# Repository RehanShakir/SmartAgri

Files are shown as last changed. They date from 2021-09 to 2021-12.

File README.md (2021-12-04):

<p align="center">
  <a href="" rel="noopener">
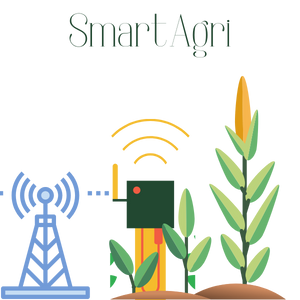
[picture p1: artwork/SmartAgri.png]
Project logo
 </a>
</p>

<h3 align="center">SmartAgri</h3>

<div align="center">

[]()

</div>

---

<p align="center"> SmartAgri
    <br> 
</p>

## 📝 Table of Contents

- [About](#about)
- [Getting Started](#getting_started)
- [Circuit](#circuit)
- [Server Details](#server)
- [MQTT Topic Details](#mqtt)
- [API Details](#api)
- [Usage](#usage)
- [List Of Components](#list)
- [Built Using](#built_using)
- [Authors](#authors)

## 🧐 About 

This repo contains

- Backend
- Firmware
- Client auto-Installer script
- Detailed instructions

for Smart SmartAgri.

## Getting Started 

These instructions will get you a copy of the project up and running on your system.

### Prerequisites

Things you need to install the FW.

```
- Arduino IDE
```

### Installing 

A step by step series that tell you how to get the Firmware and Backend running

#### ESP32 Configuration

You should have Arduino IDE Installed

1.  Add ESP32 Board to your Arduino IDE
1.  In your Arduino IDE, go to File> Preferences
    Installing ESP32 Add-on in Arduino IDE Windows, Mac OS X, Linux open preferences
1.  Enter `https://dl.espressif.com/dl/package_esp32_index.json`
    into the “Additional Board Manager URLs” field then, click the “OK” button:
    Note: if you already have the ESP32 boards URL, you can separate the URLs with a comma(each board will go to neaw line) as follows:
    `https://dl.espressif.com/dl/package_esp32_index.json,\n http://arduino.esp8266.com/stable/package_esp8266com_index.json`

1.  Open the Boards Manager. Go to Tools > Board > Boards Manager…
1.  Search for ESP32 and press install button for the ESP32 by Espressif Systems“:
1.  That’s it. It should be installed after a few seconds.
1.  In your Arduino sketchbook directory, create tools directory if it doesn't exist yet.
1.  Unpack the tool into tools directory(present in libs/ESP32FS-1.0.zip) (the path will look like <home_dir>/Arduino/tools/ESP32FS/tool/esp32fs.jar).
1.  Close and re-open the Arduino IDE.

1.  Now copy the contents of the libs folder to the libraries directory of your Arduino
    1. If you are using windows, the libraries directory will be Documents/Arduino/libraries

##### ESP32 Node FW Uploading

1.  Select ESP32 Dev Module from Tools->Board->ESP32
2.  Select the correct port from Tools->Port
3.  Then open Firmware.ino file,
4.  Select Tools > ESP32 Sketch Data Upload menu item. This should start uploading the files into ESP32 flash file system.
5.  Now Upload the Code to your ESP32 Dev Module.
6.  Your ESP32 is now ready to be used.

## Circuit 

### ESP32 Dev Module Pinout

Follow the pinout diagram given below to connect different components to your ESP32 Dev Module board.

Pinout


### Complete Circuit Diagram

Here's the complete circuit diagram of the system.

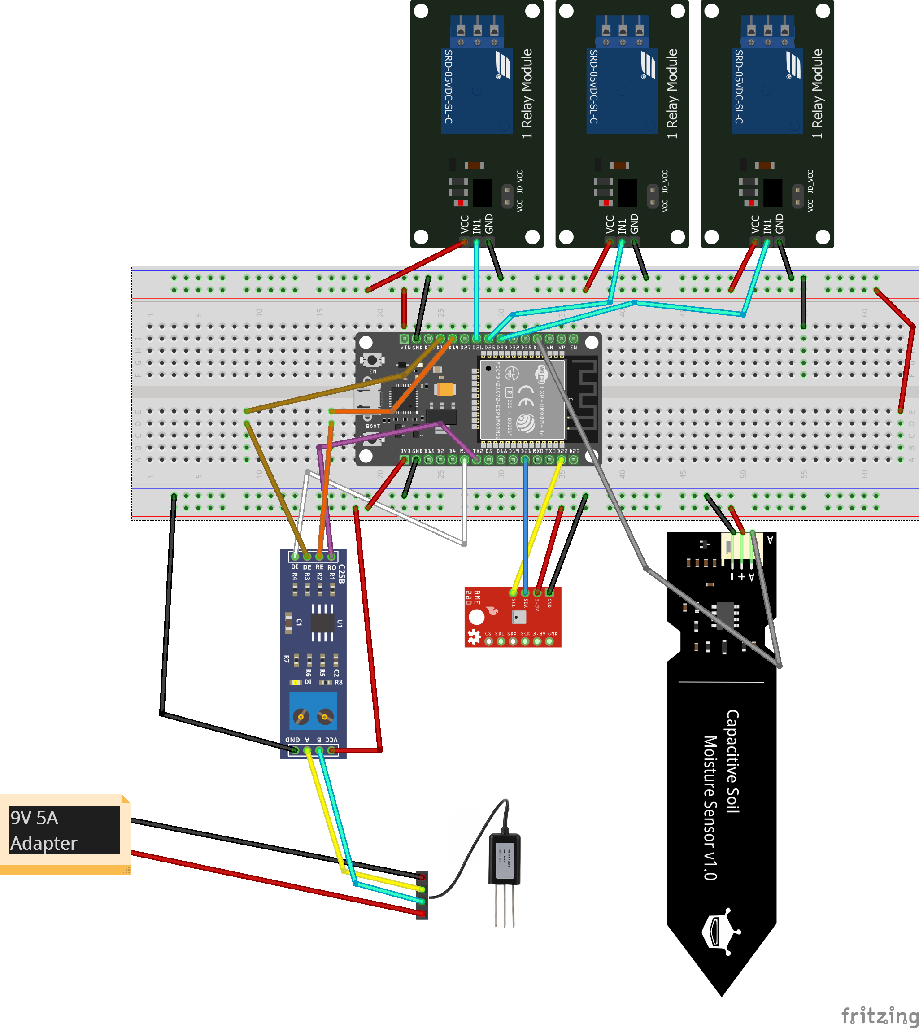
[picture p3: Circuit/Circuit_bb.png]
CircuitDiagram


## Server Details 
### Monitoring

- CapRover

### List of Packages installed on server

- Mosquitto Broker
- NodeJS, NPM, Node, NVM
- PM2
- ufw
- Caprover
- Docker
- mongod
- mongo-express

### Version Details

- Node v12.16.1
- NPM v6.13.4

### Installation of CapRover

#### Pre Reqs
-   You will need to have a domain name in order to use Caprover.
-   Ubuntu 20.04/18.04 VPS with atleast 2GB RAM and 100GB Disk Space.
-   A public IP for VPS.

####  Installation

-   Open the server terminal and execute the following commands
-   ```sudo apt install ufw```
-   ```sudo ufw allow 22```
-   ```sudo ufw allow 1883```
-   ```ufw allow 80,443,3000,996,7946,4789,2377/tcp; ufw allow 7946,4789,2377/udp;```
-   ```sudo ufw enable```
-   ```sudo apt install apt-transport-https ca-certificates curl software-properties-common```
-   ```curl -fsSL https://download.docker.com/linux/ubuntu/gpg | sudo apt-key add -```
-   ```sudo add-apt-repository "deb [arch=amd64] https://download.docker.com/linux/ubuntu focal stable"```
-   ```apt-cache policy docker-ce```
-   ```sudo apt install docker-ce```
-   ```sudo systemctl status docker```
-   The above command will show the status of Dokcer
-   ```sudo usermod -aG docker ${USER}```
-   ```su - ${USER}```
-   ```groups```
-   The above command should show something like *ubuntu sudo docker*
-   ```sudo reboot```
-   Once the server is rebooted run the following commands

##### Step 1
-   ```docker run -p 80:80 -p 443:443 -p 3000:3000 -v /var/run/docker.sock:/var/run/docker.sock -v /captain:/captain caprover/caprover```

You will see a bunch of outputs on your screen. Once the CapRover is initialized, you can visit http://[IP_OF_YOUR_SERVER]:3000 in your browser and login to CapRover using the default password captain42. You can change your password later. However, do not make any changes in the dashboard. We'll use the command line tool to setup the server.
##### Step 2

Let's say you own mydomain.com. You can set *.something.mydomain.com as an A-record in your DNS settings to point to the IP address of the server where you installed CapRover. Note that it can take several hours for this change to take into effect. It will show up like this in your DNS configs:

TYPE: A record
HOST: *.something
POINTS TO: (IP Address of your server)
TTL: (doesn't really matter)
To confirm, go to https://mxtoolbox.com/DNSLookup.aspx and enter randomthing123.something.mydomain.com and check if IP address resolves to the IP you set in your DNS. Note that randomthing123 is needed because you set a wildcard entry in your DNS by setting *.something as your host, not something.

##### Step 3
Assuming you have npm installed on your local machine (e.g., your laptop), simply run (add sudo if needed):

-   ``` sudo npm install -g caprover```
  
Then, run

- ```caprover serversetup```

Follow the steps and login to your CapRover instance. When prompted to enter the root domain, enter something.mydomain.com assuming that you set *.something.mydomain.com to point to your IP address in step #2. Now you can access your CapRover from captain.something.mydomain.com

Note: It will not be possible to carry through with the 'caprover serversetup' if you've already forced https on your CapRover instance.
In such case go straight to logging in with the caprover login command. To change the password go to the settings menu in the app.

#### Deployment

-   Once the CapRover is running, open the dashboard and create 2 new apps named
1.  smart-agri-backend
2.  smart-agri-frontend

Then create go to one click apps and search MongoDB and install it with the following settings

-   Name: smart-agri-database
-   MONGO_INITDB_ROOT_USERNAME: smartAgriDatabase
-   MONGO_INITDB_ROOT_PASSWORD: sma$r$t$Agr$iD$a$%tabase

Once done, go to Web App folder
-   Open frontend root, compress everything as .tar using 7zip or tar if using terminal
-   Open backend folder and again compress everything as .tar
-   Then in caprover open smart-agri-backend->Deployment->Upload & Deploy your .tar file, do the same for front-end as well.

### Server Links 

- MQTT Broker Link: hivemq.com
- Backend Link: http://smart-agri-backend.iot.intelligadgets.me/
- Frontend Link: https://smart-agri-frontend.iot.intelligadgets.me/

### Backend

- Backend is based on NodeJS and it is being managed by Caprover. It starts automatically on server start.

## MQTT Topic Details 

### Topics List

#### Logs

1.  <span style="color: green">smart-agri/logs</span> `(all log messages are published to this topic) READ-ONLY`

#### Fimrware

1.  <span style="color: green">smart-agri/deviceExists</span> `(Publish DeviceMAC on this topic to check if device exisits in DB) WRITE-ONLY`
    1.  <span style="color: green">smart-agri/deviceExistance</span> `(Response from the above command {null or device MAC}) READ-ONLY`

2.  <span style="color: green">data/MAC_ADDRESS</span> `(Publish data to update a device in DB based on its MAC Address.) WRITE-ONLY`
    - Data Format: 
        ```JSON
        {
        "_id":"616fb42d27d2b5351d8a013e",
        "macAddress":"240AC4AFDBDB9C",
        "FW_Version":"v1.0",
        "Environment":
        [
            {
                "Temperautre":12.1,
                "Humidity":54,
                "Atmospheric_Pressure":37.78,
                "_id":"616fb42d27d2b5351d8a013f"
            }
        ],
        "Soil_Parameters":
        [
            {
                "Soil_Moisture":5.44,
                "EC":87.52,
                "pH":47.31,
                "Nitrogen":54.64,
                "Phosphorus":97.13,
                "Potassium":51.03,
                "_id":"616fb42d27d2b5351d8a0140"
            }
        ],
        "createdAt":"2021-10-20T06:16:13.901Z",
        "updatedAt":"2021-10-20T06:16:13.901Z",
        "__v":0
        }
        ```

3.  <span style="color: green">macAddress/relay</span> `(Publish data to control a GPIO(relay/valve) based on SensorNode's MAC Address.) WRITE-ONLY`
    -   Data will be a string "1", "2" or "3"

3.  <span style="color: green">macAddress/settings</span> `(Publish data to set configuration or calibration based on SensorNode's MAC Address.) WRITE-ONLY`
    -   The settings field in the dashboard should contain a valid setting as given below
    1.  "soil_sensor=minLowValue,maxHighValue" (example: soil_sensor=0,550)
    2.  "device_operation=type (example: device_operation=restart)
## API Details 

### Live Sensor Nodes

```http
POST http://smart-agri-backend.iot.intelligadgets.me/api/mqtt
```

| Parameter | Type | Description |
| :--- | :--- | :--- |
| `nothing` | `nothing` | nothing |

-   Returns the list of live sensor nodes

### Users Register

```http
POST http://smart-agri-backend.iot.intelligadgets.me/api/users/register
```

| Parameter  | Type | Description |
| :--- | :--- | :--- |
| `email` | `email address` | **required** enter a valid email address |
| `password` | `password` | **required** enter a password |

-   User registration

### Users Register

```http
POST http://smart-agri-backend.iot.intelligadgets.me/api/users/login
```

| Parameter  | Type | Description |
| :--- | :--- | :--- |
| `email` | `email address` | **required** enter a valid email address |
| `password` | `password` | **required** enter a password |

-   User login

### Responses

Many API endpoints return the JSON representation of the resources created or edited. However, if an invalid request is submitted, or some other error occurs, Gophish returns a JSON response in the following format:

```javascript
{
  "status"  : int,
  "message" : string
}
```

The `message` attribute contains a message commonly used to indicate errors or to return the logged status/

The `status` attribute describes if the transaction was successful or not.

### Status Codes

SmartAgri Backend returns the following status codes in its API:

| Status Code | Description |
| :--- | :--- |
| 200 | `OK` |
| 201 | `CREATED` |
| 400 | `BAD REQUEST` |
| 404 | `NOT FOUND` |
| 500 | `INTERNAL SERVER ERROR` |

## Usage 

1.  Upload the code to your ESP32.
2.  Open the dashboard to monitor the parameters.
    1.  Dashboard Default credentials
        1.  Email Address: **admin@admin.com**
        2.  Password: **admin**

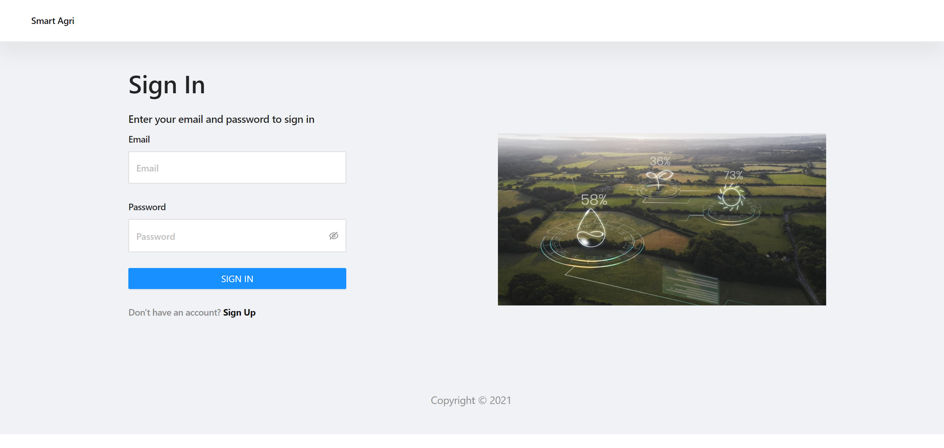
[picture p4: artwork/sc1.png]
SCRD1
Dashboard Login Page
Dashboard Signup PageSCRD2
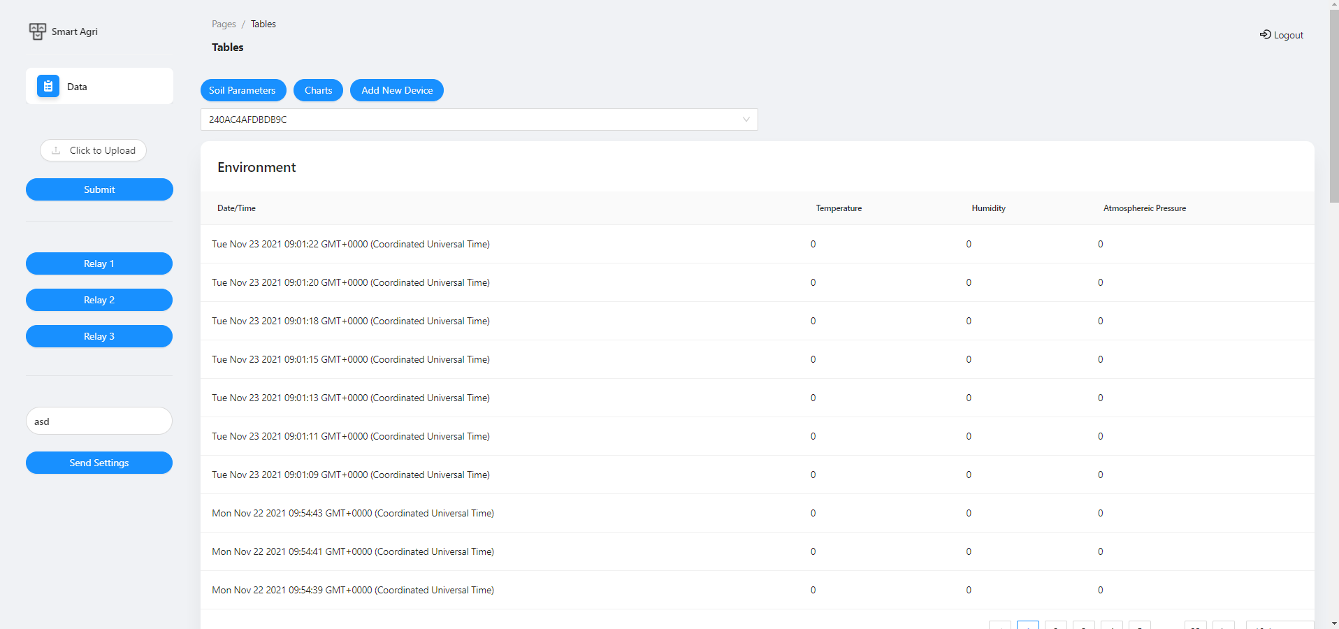
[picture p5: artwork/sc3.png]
SCRD3
Dashboard Home Page
png) 
4. Power on your ESP32, it will present you with an AP named `SmartA-abc` (while `SmartA` can be changed in the portal and `abc` is a unique id for each esp32)
5. Default captive portal password `12345678AP` which can be changed in captive portal. 
6. Connect to the ESP32 access point and open the web-browser and navigate to the link `http://esp32.local/_ac`. This link will work on most of the operating systems but if your operating system is not allowing to open it, you may want to check the captive portal IP Address from the serial monitor and can use that IP address inplace of the above mentioned URL. 
7. The default access IP Address is `http://192.168.4.1/_ac` 8. You will be presented with a main dashboard as shown below(based on your device)
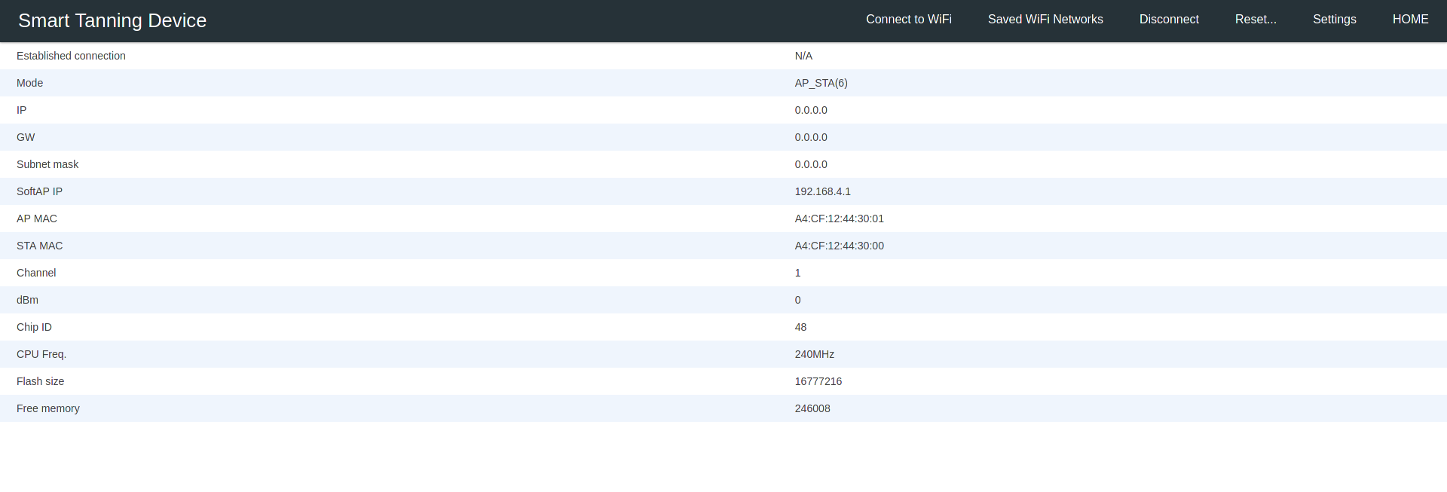
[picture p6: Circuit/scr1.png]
SCR1


8.  Once connected to a WiFi network, you can again access the captive portal using same URL or the IP Address from the Serial monitor.
9.  The data is published to the MQTT Topic `SmartA/{hostname}` while the hostname is the one which you can define in Settings page of the captive portal.
10.  You can open settings page with following default credentials
     1.  User: **AP Name (SmartA)**
     2.  Password: **admin**

## List of Components 

Following components are used to make this project

1.  ESP32 Dev Module
    ○ https://www.amazon.com/ESP32-WROOM-32-Development-ESP-32S-Bluetooth-Arduino/dp/B084KWNMM4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
2.  Atmospheric Temperature and Humidity Sensor (BME280)
    ○ https://www.amazon.com/HiLetgo-Temperature-Humidity-Electronic-Practice/dp/B0795F19W6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
3.  Capacitive Soil Moisture Sensor
    ○ https://www.amazon.com/Icstation-Resistive-Soil-Moisture-Sensor/dp/B076DDWDJK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
4.  NPK Sensor
    ○ https://www.amazon.com/Neufday-Precision-Nutrient-Intelligent-Fertilizer/dp/B0836WYNJ1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
5.  TTL to RS485 Converter
    ○ https://www.amazon.com/HiLetgo-Reciprocal-Hardware-Automatic-Converter/dp/B082Y19KV9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
6.  Soil pH Sensor
    ○ https://www.amazon.com/Taidacent-Detector-Agricultural-Phosphorus-Potassium/dp/B08MXVSKG9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
7.  Soil EC Sensor
    ○ https://www.amazon.com/Taidacent-Detector-Agricultural-Phosphorus-Potassium/dp/B08MXVSKG9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
8.  9V 5A Adapter
    ○ https://www.amazon.com/Supply-Adapter-Converter-Regulator-Monitor/dp/B0888DQ343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
9.  9V to 5V Buck Converter
    ○ https://www.amazon.com/UCTRONICS-Converter-Transformer-Voltage-Regulator/dp/B07XXWQ49N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

## ⛏️ Built Using 

- [NodeJS](https://nodejs.org/en/) - JS Framework for Backend Programming
- [Eclipse Paho MQTT](https://www.eclipse.org/paho/index.php?page=clients/python/index.php) - MQTT Client for Backend and RPiClient Software
- [Arduino](https://www.arduino.cc/) - Embedded Framework and IDE - For Sensor Node Design
- [VueJS](https://vuejs.org/) - For Dashboard Design

## ✍️ Authors 

- [@Nauman3S](https://github.com/Nauman3S) - Development and Deployment

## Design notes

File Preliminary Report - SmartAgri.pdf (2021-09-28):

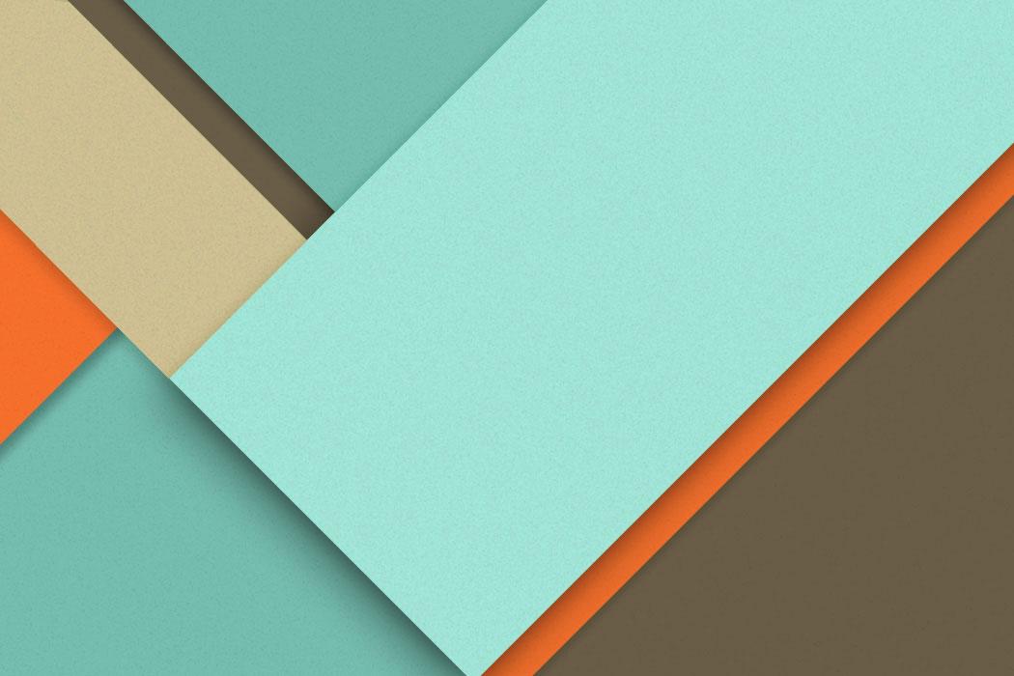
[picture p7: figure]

# SmartAgri

### Preliminary Report V1

09.09.2021
─

## Nauman Shakir

### https://NaumanShakir.com https://3STechLabs.com

## Overview

This preliminary report aims at defining an architecture for SmartAgri systems. The goals of this report are mentioned below

## Goals

1. The system should reduce the time required for a person to be in the field.
2. The system should notify the sensors’ parameters and allow control of different valves and actuators etc via web app.

## Specifications

The system is divided into 3 different layers which should communicate with each other in real-time.

## Layers

- Hardware - Sensor Nodes
- Processing Layer - Server {Ubuntu Server 18.04}
- Application Layer - Mobile and Web Apps

## Components Required

- ESP32 Dev Module
- https://www.amazon.com/ESP32-WROOM-32-Development-ESP-32S-Bluetooth-Arduino/dp/B084KWNMM4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 (https://www.amazon.com/ESP32-WROOM-32-Development-ESP-32S-Bluetooth-Arduino/dp/B084KWNMM4)
- Atmospheric Temperature and Humidity Sensor (DHT22)
- https://www.amazon.com/HiLetgo-Temperature-Humidity-Electronic-Practice/dp/B0795F19W6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 (https://www.amazon.com/HiLetgo-Temperature-Humidity-Electronic-Practice/dp/B0795F19W6)
- Atmospheric Pressure Sensor
- https://www.amazon.com/Gikfun-Barometric-Pressure-Temperature-EK1214x3/dp/B07Q3PQ81R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 (https://www.amazon.com/Gikfun-Barometric-Pressure-Temperature-EK1214x3/dp/B07Q3PQ81R)
- Soil Moisture Sensor
- https://www.amazon.com/Icstation-Resistive-Soil-Moisture-Sensor/dp/B076DDWDJK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 (https://www.amazon.com/Icstation-Resistive-Soil-Moisture-Sensor/dp/B076DDWDJK)
- NPK Sensor
- https://www.amazon.com/Neufday-Precision-Nutrient-Intelligent-Fertilizer/dp/B0836WYNJ1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 (https://www.amazon.com/Neufday-Precision-Nutrient-Intelligent-Fertilizer/dp/B0836WYNJ1)
- RS485 Converter for NPK Sensor
- https://www.amazon.com/Max485-Chip-RS-485-Module-Raspberry/dp/B00NIOLNAG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 (https://www.amazon.com/Max485-Chip-RS-485-Module-Raspberry/dp/B00NIOLNAG)
- Soil pH Sensor
- https://www.amazon.com/Taidacent-Detector-Agricultural-Phosphorus-Potassium/dp/B08MXVSKG9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 (https://www.amazon.com/Taidacent-Detector-Agricultural-Phosphorus-Potassium/dp/B08MXVSKG9)
- Soil EC Sensor
- https://www.amazon.com/Taidacent-Detector-Agricultural-Phosphorus-Potassium/dp/B08MXVSKG9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 (https://www.amazon.com/Taidacent-Detector-Agricultural-Phosphorus-Potassium/dp/B08MXVSKG9)
- 9V 5A Adapter
- https://www.amazon.com/Supply-Adapter-Converter-Regulator-Monitor/dp/B0888DQ343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 (https://www.amazon.com/Supply-Adapter-Converter-Regulator-Monitor/dp/B0888DQ343)

- 9V to 5V Buck Converter
- https://www.amazon.com/UCTRONICS-Converter-Transformer-Voltage-Regulator/dp/B07XXWQ49N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 (https://www.amazon.com/UCTRONICS-Converter-Transformer-Voltage-Regulator/dp/B07XXWQ49N)

## Architecture

The complete project has multiple components
- Sensor Nodes
- IoT Server

Sensor Nodes are small boxes containing esp32, Modubus to Serial adapters, and a connector for the sensors. While for the power a 9v 5A adapter is required.

## Sensor Nodes Architecture

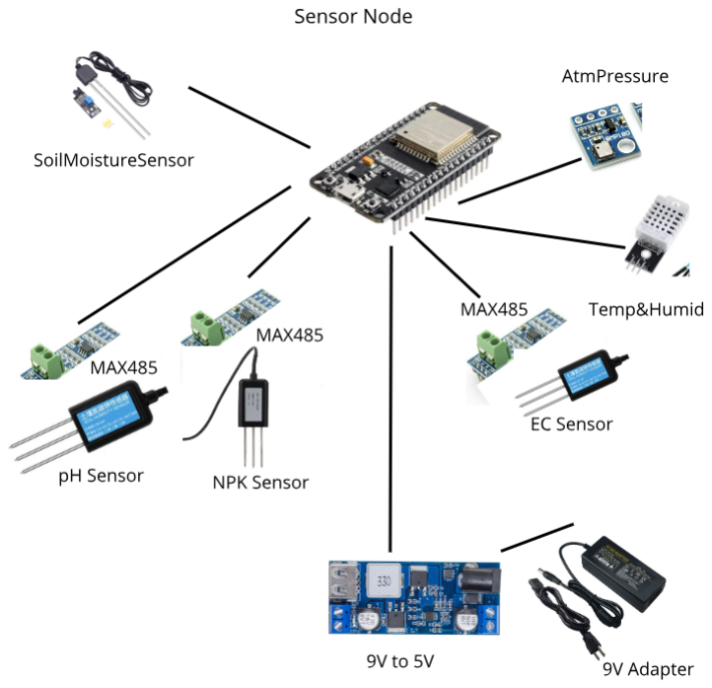
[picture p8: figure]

Above is the Sensor Nodes architecture. Each box contains a single sensors along with ESP32.
The whole assembly with sensors along with a Master(ESP32) is referred to as a sensor node.

## System Architecture

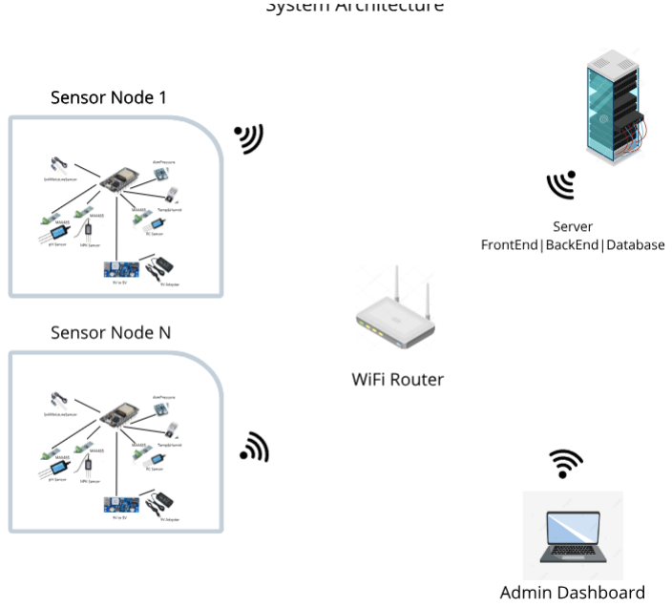
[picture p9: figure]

Above shown is the complete system architecture. Each Sensor Node can communicate with the server via MQTT(it is best to use MQTT for data communication because it is low-powered) and the IoT server exposes an OTA API as well. The web app can get the live data from the IoT Server.

## Software Architecture

### Multiple Nodes management

The nodes should have unique identifiers which are the MAC address numbers of ESP32 which will be used to uniquely identify each Node.
SensorNodeID;[DataString]
- SensorNodeID is a unique ID of Sensor Node
- [DataString] contains the sensor value(Status)
The communication is done over WiFi and data is shared to the IOT Server(and the webapp) over MQTT.

### Web Server Integration

The communication should ideally be done using MQTT because of its smaller data packets and fast response. Your webapp or smartphone app will communicate with the IOT Server instead of communicating directly with the Sensor Nodes. This can save power and can make the communication and OTA fast.

## What is MQTT?

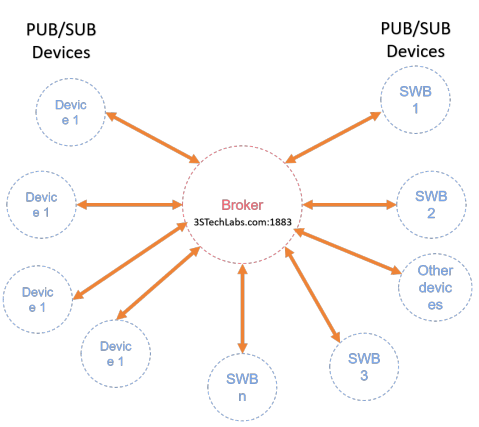
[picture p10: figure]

Take an example of a system in which there are hundreds of people having smart bands that can display information of a person’s surroundings. And then there are Android, iOS and Windows devices that can be used to monitor smart bands to define set of parameters for bands.
So in a scenario where there are mixed types of devices including hardware platforms, the best communication protocol is MQTT.
It can handle two-way and parallel communication and the number of devices that can be connected and communicate via MQTT are limitless, the only limit is server resources. MQTT is also known as pub/sub protocol.
Hence the protocol of choice here is MQTT.

## WebApp

The web app will be made using VueJS for frontEnd, NodeJS and FastAPI for BackEnd and Mongo DB for the database.
I will use CreativeTim dashboard template (https://www.creative-tim.com/product/vue-material-dashboard) to create a nice-looking management portal. Sample preview of the dashboard is shown below

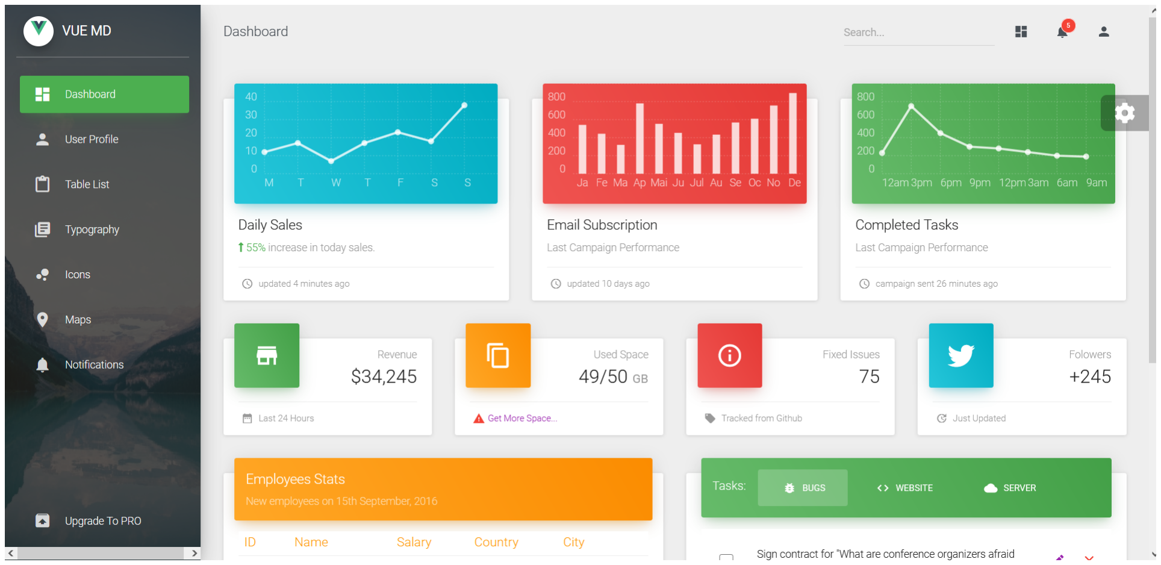
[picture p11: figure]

### Features of the WebApp

1. Minimalistic design
2. User login/signup
3. Device addition deletion
4. Real-time devices monitoring
5. Setting up alarms

## Management and CI/CD Pipeline

We will use Github for delivering the code. The developers from my team will be working on Hardware, Firmware, Backend, Frontend and apps simultaneously and for modularity we will dockerize different components of the app.
For Continuous Integration and Delivery we will be using CapRover running on a bare metal Ubuntu 18.04 instance and each component of the project’s github repository will be linked to the respective Containers running in the Caprover. It will allow fully-automated delivery. We will use our own company’s production server running on AWS for testing and delivery during the development time. After that we can transfer the files to your own AWS and details of migration are mentioned in the Terms and Condition section of this report.
My automation engineer will work on this.

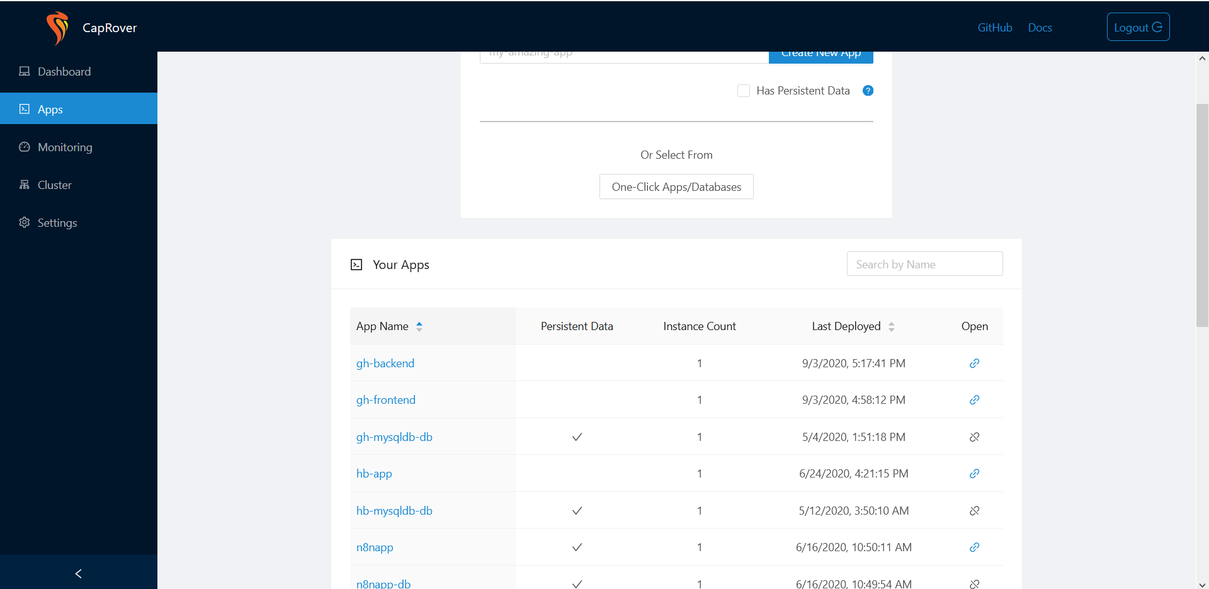
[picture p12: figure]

From the picture above you can see that all of the services like backend, frontend and database etc are running in separate containers allowing a smooth delivery pipeline.

### 3STechLabs’ CI/CD Standard Pipeline

Below is our well-tested CI/CD Pipeline for project management and delivery. This has been proven to work for our 10+ Full-Stack IoT Projects and Products.

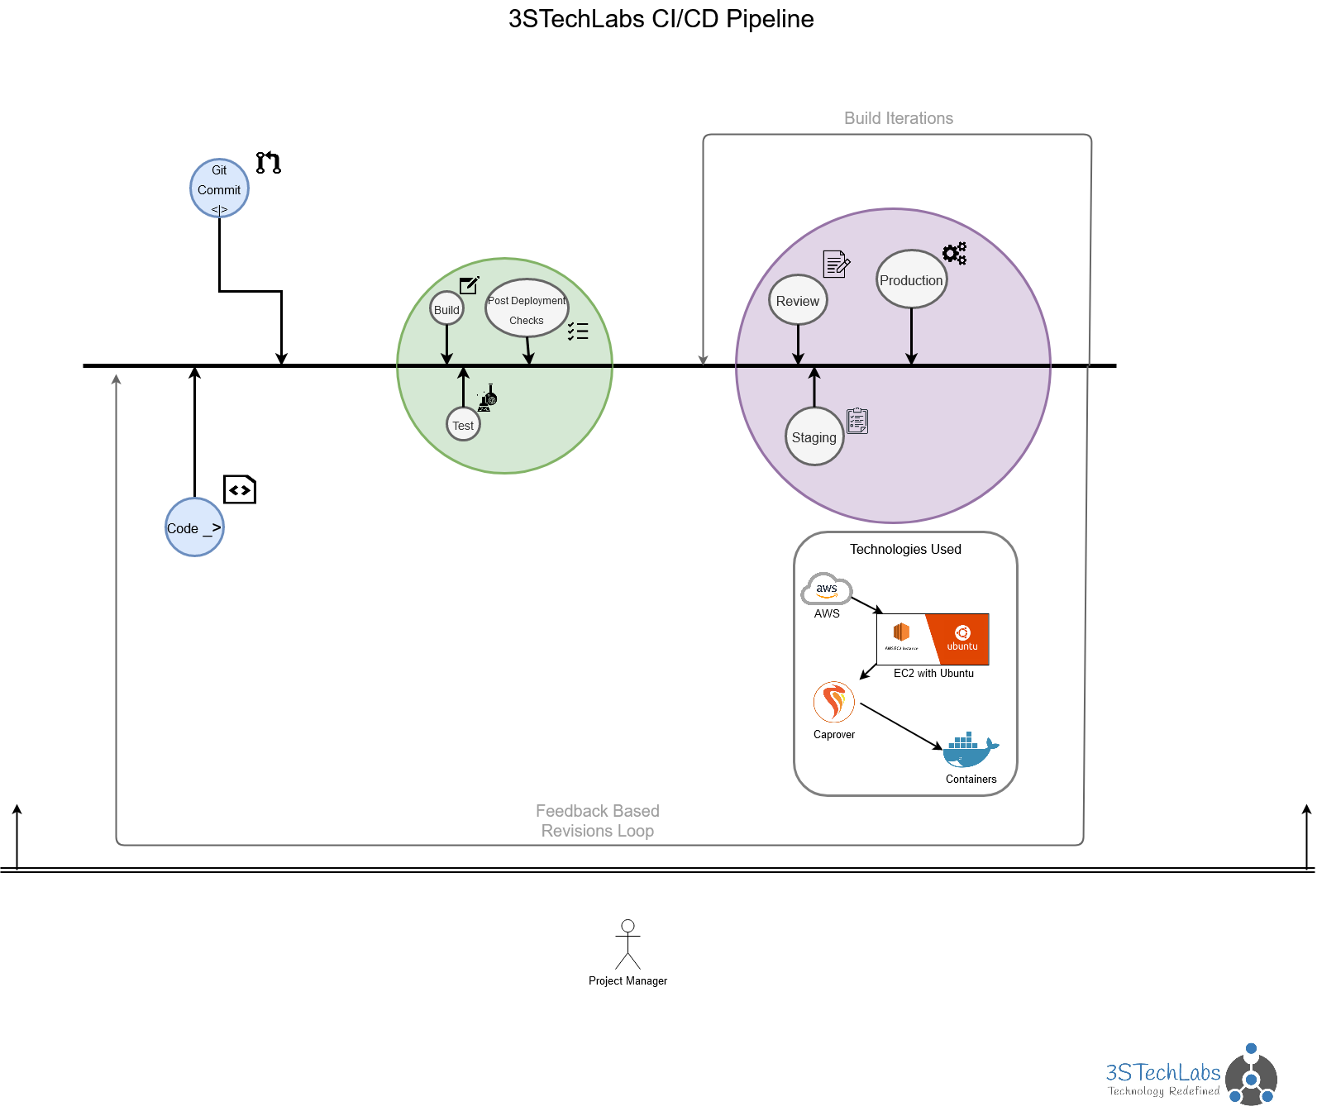
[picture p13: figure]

(For a detailed look, please open the image file of above diagram)

## Questions and Their Answers

### 1. Could you develop a prototype for us?

- Do you want me to send you the completed prototype to your address? If yes, unfortunately, I can’t do this at this moment and neither can I commit anything like that because of the current Covid-19 situation the flights are delayed eventually delaying the shipments and in some cases even missing the delivery altogether.
- On other hand, I will provide you
- Complete Code
- Circuit diagrams
- A complete report on how to setup and configure things.
- You can use all the delivered files and documentation to assemble. the prototype yourself.

## Milestones Breakdown

1. Sensor NodesDesign - Milestone 1 | | $350
a. Hardware and Firmware with WiFi Manager + Setup Document
b. Development Time 15 Days
2. IoT Server Design and Configuration - Milestone 2 | $460
a. WebServer backend and other related things + Setup Document
b. Development Time 20 Days
3. WebApp Dashboard Design | Milestone 3 | $0
a. Based on the CreativeTim dashboard
b. Development Time 12 days
c. *This milestone will be developed for free.

Terms and Conditions

- We will not ship anything physically unless otherwise decided, instead, you will be provided with a setup document with the completion of each milestone which will be easy to follow and will contain all of the necessary information.

In this document, the company refers to 3STechLabs.

If you agree to this report please fill-out the form below.

https://naumanshakir3s.typeform.com/to/jZJlJP

## Profile

Name: Nauman Shakir
Company: 3STechLabs
Designation: Founder and Program Manager
Email Address: NaumanShakir3S@gmail.com
Portfolio: https://NaumanShakir.com
I’m a Full-Stack IoT Developer and have done more than 150 hardware projects and running an IoT and Hardware Design House https://3STechLabs.com
https://facebook.com/3STechLabshttps://Linkedin.com/company/3STechLabs

Freelancing Profiles
https://www.fiverr.com/naumanshakirhttps://www.upwork.com/fl/naumanshakir3s

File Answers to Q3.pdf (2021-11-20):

1. I could successfully connect to my WiFi network using Autoconnect. However, if the device power is turned off, it doesn’t reconnect to the saved WiFi network upon power on. It is very important to reconnect to a saved network as this device is used standalone without the user nearby.

A: it should be connected to the saved WiFi network once you restart it. The reason why it is not connecting again might be because you are getting very low signal strength from your WiFi router.

2. The code seems to be for using the NPK, BME280 and soil moisture sensors together. Since all users will not be using all the sensors, please provide information on how to disable unwanted sensors?

A: I have already placed the fail-safe checks in the Firmware. If the firmware doesn’t detect any sensor it will report 0 values for it and will keep working with other sensors.

3. As agreed with you, in the below code for soil moisture sensor, the values 550,0 is dependent on several factors and may have to be changed depending on the environment, type of soil etc. Hence, I would like this value to be fetched from the website instead of hardcoding. int sensor_pin = 2; int value; void setupSoilMoisture() { } String getSoilMoisture() { value = analogRead(sensor_pin); value = map(value, 550, 0, 0, 100); Serial.print("Moisture : "); Serial.print(value); Serial.println("%"); delay(10); return String(value); }

A: Sure, we can work on that.

4. The BME280 sensor values are not showing. It always shows in Serial Monitor that the sensor is not connected. I checked the connections and found all were fine.

A: Done. I have updated the firmware and it should work now.

5. What is this link in the code “broker.hivemq.com”? Is this a third-party service?

A: It is used to allow devices and websites to communicate with each other. It is a free service and acts as middleware between devices, apps, and websites etc. If you want to use your personal MQTT Broker in place of this free service, you can follow this guide http://www.steves-internet-guide.com/install-mosquitto-linux/ and then use the created address in place of broker.hivemq.com.

6. Please provide the complete installation procedure in case, for example, I reinstall OS in my VPS. I can do the CapRover installation, but the .tar file installation I did was not successful, and you had done some changes to get things working. Hence, please provide detailed information, and I would like to try doing a reinstallation from my side.

A: Done. I have added the complete instructions in the new README.pdf file

7. Mobile App:-
a. Please include option to save login username and password in the mobile app.
A: I will check with my developer if it is possible, I will do that.
b. The date shown in the x-axis is very congested in the mobile app(this is the same in webapp also when viewed in smaller screen). Generally, the app looks like the website converted to app. Is there anything which can be done to improve the graph display? Please see the below image
A: Updating it.
c. We had discussed mobile app and not just Android app. So, both iOS and Android apps were expected.
A: Although there was no mention of iOS app in our discussion and it is a standard practice to provide the android app. But now I have built the iOS app as well. You can find it in the smartphone directory. I don’t have MacBook to compile it so you can just copy the iOS folder to any MacBook with xcode and click compile/build and it will be ready in few minutes.
d. How can I add my logo in the mobile app (Also in the WebApp)
A: You should have provided the logos at the start of the project. The whole project now needs to be recompiled with new logos in order to change them,
8. My data is not showing in the backend now in the links (http://smart-agribackend.iot.intelligadgets.me/api/mqtt. I tried both firmwares
MQTTPubFW.ino and the Firmware.ino. Earlier it worked when I used MQTTPubFW.ino. My serial monitor shows as below
A: The firmware seems to be working fine I am using the same firmware and you can see my devices in the dashboard. Let me check with my developer to fix your device issue.
9. How to use the OTA? What format file should I upload, how to create the file and how it works? Is it operational already?
A: Open Arduino IDE, go to Sketch menu and click on export compiled binary. It will output a .bin file, upload it to the dashboard and click submit. Now the OTA file is stored in the server. We need ssh access to your server to prepare it for broadcasting OTA file.
On-device side you will be able to see something like this https://hieromon.github.io/AutoConnect/images/serverupdate.gif
10. Now devices in the website are represented by Mac addresses. Can we add a name for each Mac address? If a user has more than one device, it is difficult to identify with Mac address
A: yes it is possible but it will require modifications both in the backend and frontend.
11. In the soil parameters graph, the categories on the right is showing “Temperature” “Humidity” and “Atmospheric Pressure”. This needs to be changed to pH, EC, and N, P, K. Also, the chart is not showing “Potassium
A: Updating it

12. Please add date / time in the table and date in chart also as the time of reading cannot be identified from the current table.
A: Updating it
13. The link is too long now (https://smart-agri-frontend.iot.intelligadgets.me/tables). How can I change it to something like https://dashboard.iot.intelligadgets.me ?
A: You will need to redirect the original link to anything shorter in you domain provider dashboard. See redirections in domain records for more details.
14. How can I delete a device Mac Address from the drop down if it is no more used or damaged
A: Not possible for now maybe an expiration time can be added if device is not used for mayeb one week or one month.

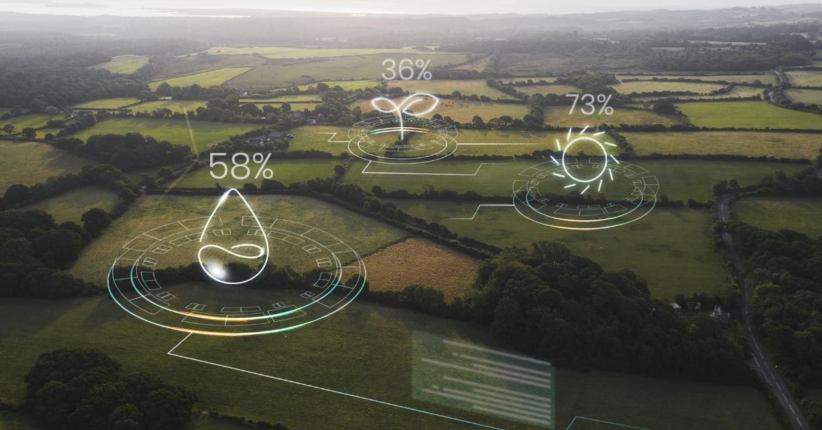
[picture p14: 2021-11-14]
Web App/Frontend/src/assets/images/smartFarmingIot.jpg

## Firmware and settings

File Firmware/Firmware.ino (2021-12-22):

#include "headers.h" //all misc. headers and functions
#include "dataHandler.h"
#include "MQTTFuncs.h" //MQTT related functions
#include "webApp.h"    //Captive Portal webpages
#include <FS.h>        //ESP32 File System
#include "commHandler.h"
#include "BMEHandler.h"
#include "soilMoistureHandler.h"

IPAddress ipV(192, 168, 4, 1);
char npkData[2024] = {"0.0,0.0,0.0"};
TaskHandle_t npkTask;
String loadParams(AutoConnectAux &aux, PageArgument &args) //function to load saved settings
{
    (void)(args);
    File param = FlashFS.open(PARAM_FILE, "r");
    String v1 = "";
    String v2 = "";
    if (param)
    {
        Serial.println("load params func");
        aux.loadElement(param);

        // curSValueElm.value="CurS:7788";
        param.close();
    }
    else
        Serial.println(PARAM_FILE " open failed");
    return String("");
}

String saveParams(AutoConnectAux &aux, PageArgument &args) //save the settings
{
    serverName = args.arg("mqttserver"); //broker
    serverName.trim();

    channelId = args.arg("channelid");
    channelId.trim();

    userKey = args.arg("userkey"); //user name
    userKey.trim();

    apiKey = args.arg("apikey"); //password
    apiKey.trim();

    apPass = args.arg("apPass"); //ap pass
    apPass.trim();

    settingsPass = args.arg("settingsPass"); //ap pass
    settingsPass.trim();

    hostName = args.arg("hostname");
    hostName.trim();

    // The entered value is owned by AutoConnectAux of /mqtt_setting.
    // To retrieve the elements of /mqtt_setting, it is necessary to get
    // the AutoConnectAux object of /mqtt_setting.
    File param = FlashFS.open(PARAM_FILE, "w");
    portal.aux("/mqtt_setting")->saveElement(param, {"mqttserver", "channelid", "userkey", "apikey", "hostname", "apPass", "settingsPass"});
    param.close();

    // Echo back saved parameters to AutoConnectAux page.
    AutoConnectText &echo = aux["parameters"].as<AutoConnectText>();
    echo.value = "Server: " + serverName + "<br>";
    echo.value += "Channel ID: " + channelId + "<br>";
    echo.value += "Username: " + userKey + "<br>";
    echo.value += "Password: " + apiKey + "<br>";
    echo.value += "ESP host name: " + hostName + "<br>";
    echo.value += "AP Password: " + apPass + "<br>";
    echo.value += "Settings Page Password: " + settingsPass + "<br>";

    return String("");
}
bool loadAux(const String auxName) //load defaults from data/*.json
{
    bool rc = false;
    Serial.println("load aux func");
    String fn = auxName + ".json";
    File fs = FlashFS.open(fn.c_str(), "r");
    if (fs)
    {
        rc = portal.load(fs);
        fs.close();
    }
    else
        Serial.println("Filesystem open failed: " + fn);
    return rc;
}
uint8_t inAP = 0;
bool whileCP()
{

    if (inAP == 0)
    {
        ledState(AP_MODE);
        inAP = 1;
    }
    // Serial.println("AP MODE");

    loopLEDHandler();
}
void getNPKData()
{
    String message = "";
    if (queue != NULL)
    {
        char element[2024];
        xQueueReceive(queue, &element, (TickType_t)(100 / portTICK_PERIOD_MS));
        message = String(element);
        String n = ss.StringSeparator(message, ';', 0);
        String p = ss.StringSeparator(message, ';', 1);
        String k = ss.StringSeparator(message, ';', 2);
        setN(n);
        setP(p);
        setK(k);
    }
}
void loopNPKSensor(void *pvParameters)
{

    setupCommsHandler();
    for (;;)
    {
        getNPK();
        vTaskDelay(1000 / portTICK_PERIOD_MS);
    }
}
void setup() //main setup functions
{
    Serial.begin(115200);

    setupBME280();
    setupSoilMoisture();
    Serial.print("MAC Address: ");
    Serial.println(ss.getMacAddress());
    pinMode(R1, OUTPUT);
    pinMode(R2, OUTPUT);
    pinMode(R3, OUTPUT);

    queue = xQueueCreate(1, sizeof(npkData));
    if (queue == NULL)
    {
        Serial.println("Error creating the queue");
    }

    xQueueSend(queue, &npkData, portMAX_DELAY);

    xTaskCreatePinnedToCore(
        loopNPKSensor, /* Task function. */
        "Twitter",     /* name of task. */
        10000,         /* Stack size of task */
        NULL,          /* parameter of the task */
        1,             /* priority of the task */
        &npkTask,      /* Task handle to keep track of created task */
        1);
    delay(500);
    delay(1000);

    if (!MDNS.begin("esp32")) //starting mdns so that user can access webpage using url `esp32.local`(will not work on all devices)
    {
        Serial.println("Error setting up MDNS responder!");
        while (1)
        {
            delay(1000);
        }
    }
#if defined(ARDUINO_ARCH_ESP8266)
    FlashFS.begin();
#elif defined(ARDUINO_ARCH_ESP32)
    FlashFS.begin(true);
#endif
    loadAux(AUX_MQTTSETTING);
    loadAux(AUX_MQTTSAVE);
    AutoConnectAux *setting = portal.aux(AUX_MQTTSETTING);
    if (setting) //get all the settings parameters from setting page on esp32 boot
    {
        Serial.println("Setting loaded");
        PageArgument args;
        AutoConnectAux &mqtt_setting = *setting;
        loadParams(mqtt_setting, args);
        AutoConnectInput &hostnameElm = mqtt_setting["hostname"].as<AutoConnectInput>();
        AutoConnectInput &apPassElm = mqtt_setting["apPass"].as<AutoConnectInput>();
        AutoConnectInput &serverNameElm = mqtt_setting["mqttserver"].as<AutoConnectInput>();
        AutoConnectInput &channelidElm = mqtt_setting["channelid"].as<AutoConnectInput>();
        AutoConnectInput &userkeyElm = mqtt_setting["userkey"].as<AutoConnectInput>();
        AutoConnectInput &apikeyElm = mqtt_setting["apikey"].as<AutoConnectInput>();
        AutoConnectInput &settingsPassElm = mqtt_setting["settingsPass"].as<AutoConnectInput>();
        //vibSValueElm.value="VibS:11";
        serverName = String(serverNameElm.value);
        channelId = String(channelidElm.value);
        userKey = String(userkeyElm.value);
        apiKey = String(apikeyElm.value);
        hostName = String(hostnameElm.value);
        apPass = String(apPassElm.value);
        settingsPass = String(settingsPassElm.value);
        if (hostnameElm.value.length())
        {
            //hostName=hostName+ String("-") + String(GET_CHIPID(), HEX);
            //;
            //portal.config(hostName.c_str(), apPass.c_str());
            // portal.config(hostName.c_str(), "123456789AP");
            config.apid = hostName + "-" + String(GET_CHIPID(), HEX);
            config.password = apPass;
            config.psk = apPass;
            // portal.config(hostName.c_str(), "123456789AP");
            Serial.println("(from hostELM) hostname set to " + hostName);
        }
        else
        {

            // hostName = String("OEE");;
            // portal.config(hostName.c_str(), "123456789AP");
            config.apid = hostName + "-" + String(GET_CHIPID(), HEX);
            config.password = apPass;
            config.psk = apPass;
            //config.hostName = hostName;//hostnameElm.value+ "-" + String(GET_CHIPID(), HEX);
            // portal.config(hostName.c_str(), "123456789AP");
            Serial.println("hostname set to " + hostName);
        }
        config.homeUri = "/_ac";
        config.apip = ipV;

        portal.on(AUX_MQTTSETTING, loadParams);
        portal.on(AUX_MQTTSAVE, saveParams);
    }
    else
    {
        Serial.println("aux. load error");
    }
    //config.homeUri = "/_ac";
    config.apip = ipV;
    config.autoReconnect = true;
    config.reconnectInterval = 1;
    Serial.print("AP: ");
    Serial.println(hostName);
    Serial.print("Password: ");
    Serial.println(apPass);
    config.title = "Smart Agri Device"; //set title of webapp
    Serial.print("Device Hostname: ");
    Serial.println(hostName);
    //add different tabs on homepage

    //  portal.disableMenu(AC_MENUITEM_DISCONNECT);
    server.on("/", handleRoot);
    // Starts user web site included the AutoConnect portal.

    config.auth = AC_AUTH_DIGEST;
    config.authScope = AC_AUTHSCOPE_PARTIAL;
    config.username = hostName;
    config.password = settingsPass;

    portal.config(config);
    portal.whileCaptivePortal(whileCP);
    portal.onDetect(atDetect);
    portal.load(FPSTR(PAGE_AUTH));
    if (portal.begin())
    {
        Serial.println("Started, IP:" + WiFi.localIP().toString());
        ledState(AP_MODE);
    }
    else
    {
        Serial.println("Connection failed.");
        while (true)
        {
            yield();
            delay(100);
        }
    }

    MDNS.addService("http", "tcp", 80);
    mqttConnect(); //start mqtt

    mqttPublish("smart-agri/deviceExists", ss.getMacAddress());
}

void loop()
{
    server.handleClient();
    portal.handleRequest();

    if (millis() - lastPub > updateInterval) //publish data to mqtt server
    {
        // mqttPublish("smart-agri/" + String(hostName) + String("bme280/"), String(getBMEVal()));             //publish data to mqtt broker
        // mqttPublish("smart-agri/" + String(hostName) + String("npk/"), String(getNPK()));                   //publish data to mqtt broker
        // mqttPublish("smart-agri/" + String(hostName) + String("soilMoisture/"), String(getSoilMoisture())); //publish data to mqtt broker
        String bme = getBMEVal();
        getNPKData();
        payloadVal[0] = ss.StringSeparator(bme, ';', 0);
        payloadVal[1] = ss.StringSeparator(bme, ';', 1);
        payloadVal[2] = ss.StringSeparator(bme, ';', 2);
        payloadVal[3] = String(getSoilMoisture());
        payloadVal[4] = String("0.0");
        payloadVal[5] = String("0.0");
        payloadVal[6] = getN();
        payloadVal[7] = getP();
        payloadVal[8] = getK();

        if (digitalRead(R1) == 1)
        {
            payloadVal[9] = "On";
        }
        else
        {
            payloadVal[9] = "Off";
        }

        if (digitalRead(R2) == 1)
        {
            payloadVal[10] = "On";
        }
        else
        {
            payloadVal[10] = "Off";
        }

        if (digitalRead(R3) == 1)
        {
            payloadVal[11] = "On";
        }
        else
        {
            payloadVal[11] = "Off";
        }

      
        payloadVal[12] = settingsMsg;

        sendData(ss.StringSeparator(bme, ';', 0), ss.StringSeparator(bme, ';', 1), ss.StringSeparator(bme, ';', 2), String(getSoilMoisture()), String("0.0"), String("0.0"), getN(), getP(), getK(), payloadVal[9],payloadVal[10],payloadVal[11], settingsMsg);
        //send values
        ledState(ACTIVE_MODE);

        lastPub = millis();
    }
    if (!mqttClient.connected())
    {
        reconnect();
    }
    mqttClient.loop();
    if (WiFi.status() == WL_IDLE_STATUS)
    {
        ledState(IDLE_MODE);
        ESP.restart();

        delay(1000);
    }
}

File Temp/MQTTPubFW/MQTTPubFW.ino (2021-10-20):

/*
 Basic ESP8266 MQTT example
 This sketch demonstrates the capabilities of the pubsub library in combination
 with the ESP8266 board/library.
 It connects to an MQTT server then:
  - publishes "hello world" to the topic "outTopic" every two seconds
  - subscribes to the topic "inTopic", printing out any messages
    it receives. NB - it assumes the received payloads are strings not binary
  - If the first character of the topic "inTopic" is an 1, switch ON the ESP Led,
    else switch it off
 It will reconnect to the server if the connection is lost using a blocking
 reconnect function. See the 'mqtt_reconnect_nonblocking' example for how to
 achieve the same result without blocking the main loop.
 To install the ESP8266 board, (using Arduino 1.6.4+):
  - Add the following 3rd party board manager under "File -> Preferences -> Additional Boards Manager URLs":
       http://arduino.esp8266.com/stable/package_esp8266com_index.json
  - Open the "Tools -> Board -> Board Manager" and click install for the ESP8266"
  - Select your ESP8266 in "Tools -> Board"
*/
#define BUILTIN_LED 2
#include <WiFi.h>
#include <PubSubClient.h>
#include <ArduinoJson.h>
#include "SoftwareStack.h"

// Update these with values suitable for your network.

const char* ssid = "hotspot2";
const char* password = "abc123098a#";
const char* mqtt_server = "broker.hivemq.com";
IPAddress ip(34,214,65,82);
WiFiClient espClient;
PubSubClient client(espClient);
unsigned long lastMsg = 0;
#define MSG_BUFFER_SIZE	(50)
char msg[MSG_BUFFER_SIZE];
int value = 0;
//StaticJsonDocument<256> doc;
DynamicJsonDocument doc(1024);
SoftwareStack ss;
String myMac="";


void setup_wifi() {

  delay(10);
  // We start by connecting to a WiFi network
  Serial.println();
  Serial.print("Connecting to ");
  Serial.println(ssid);

  WiFi.mode(WIFI_STA);
  WiFi.begin(ssid, password);

  while (WiFi.status() != WL_CONNECTED) {
    delay(500);
    Serial.print(".");
  }

  randomSeed(micros());

  Serial.println("");
  Serial.println("WiFi connected");
  Serial.println("IP address: ");
  Serial.println(WiFi.localIP());
  myMac=ss.getMacAddress();
  Serial.println(myMac);
}

void callback(char* topic, byte* payload, unsigned int length) {
  Serial.print("Message arrived [");
  Serial.print(topic);
  Serial.print("] ");
  for (int i = 0; i < length; i++) {
    Serial.print((char)payload[i]);
  }
  Serial.println();

  // Switch on the LED if an 1 was received as first character
  if ((char)payload[0] == '1') {
    digitalWrite(BUILTIN_LED, LOW);   // Turn the LED on (Note that LOW is the voltage level
    // but actually the LED is on; this is because
    // it is active low on the ESP-01)
  } else {
    digitalWrite(BUILTIN_LED, HIGH);  // Turn the LED off by making the voltage HIGH
  }

}

void reconnect() {
  // Loop until we're reconnected
  while (!client.connected()) {
    Serial.print("Attempting MQTT connection...");
    // Create a random client ID
    String clientId = "ESP8266Client-";
    clientId += String(random(0xffff), HEX);
    // Attempt to connect
    if (client.connect(clientId.c_str())) {
      Serial.println("connected");
      // Once connected, publish an announcement...
      client.publish("outTopic", "hello world");
      // ... and resubscribe
     // client.subscribe("inTopic");
    } else {
      Serial.print("failed, rc=");
      Serial.print(client.state());
      Serial.println(" try again in 5 seconds");
      // Wait 5 seconds before retrying
      delay(5000);
    }
  }
}

void setup() {
  pinMode(BUILTIN_LED, OUTPUT);     // Initialize the BUILTIN_LED pin as an output
  Serial.begin(115200);
  setup_wifi();
  client.setServer(ip, 1883);
  client.setCallback(callback);
}

char jsonDoc[1024];
void genJSON(){

    // doc["Timestamp"] = String("12/2/2 03:11:33");
    // doc["MAC_Address"] =myMac;
    doc["FW_Version"] = String("v1.0");
    
    
    
    doc["Environment"][0]["Temperautre"]=12.1;
    doc["Environment"][0]["Humidity"]=54;
    doc["Environment"][0]["Atmospheric_Pressure"]=37.78;
    
    doc["SoilParameters"][0]["Soil_Moisture"]=5.44;
    doc["SoilParameters"][0]["EC"]=87.52;
    doc["SoilParameters"][0]["pH"]=47.31;
    doc["SoilParameters"][0]["Nitrogen"]=54.64;
    doc["SoilParameters"][0]["Phosphorus"]=97.13;
    doc["SoilParameters"][0]["Potassium"]=51.03;
    serializeJson(doc, Serial);
}
void loop() {

  if (!client.connected()) {
    reconnect();
  }
  client.loop();

  unsigned long now = millis();
  if (now - lastMsg > (60*1000)) {
    lastMsg = now;
  
    genJSON();
    serializeJson(doc, jsonDoc);
    String topicP=String("data/")+myMac;
    Serial.print("Publishing on: ");
    Serial.println(topicP);
    client.publish(topicP.c_str(), jsonDoc);
    client.publish("mac/add/ress", jsonDoc);
    
  }
}

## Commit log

2021-09-28 added readme, fw, ckt
    [Circuit.fzz]
2021-09-28 updated fw,readme
    [Circuit.fzz]
2021-12-04 updated fw, circuit
    [Circuit.fzz]
2021-12-13 updated fw and circuit diagram to use pin34 for soil moisture sensor
    [Circuit.fzz]
2021-12-22 updated fw to save and send relay states and settings params
2021-12-22 Actuators Addred
